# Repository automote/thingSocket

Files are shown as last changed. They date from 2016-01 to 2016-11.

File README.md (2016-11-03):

# thingSocket
__thingSocket__ is a Wi-Fi enabled socket/plug coupled with open APIs for people to develop, deploy or even clone.

__thingSocket__ is an attempt to promote IoT by providing open and hackable devices that you use everyday. Devices like bulbs, sockets, presence detectors and many more. The idea revolves around identifying frequently accessed devices and converting them into IoT devices by adding Wi-Fi, BLE or ZigBee capabilities.

We are starting with a Wi-Fi Socket and a Wi-Fi Bulb. These devices have the crowd favourite ESP8266 modules and we are planning to keep the hardware and software design open. This would encourage school and college students and even IoT enthusiasts to get into the IoT Bandwagon.

## Software
The software is completely written in __Arduino IDE__, so anyone familiar with the IDE can tinker with the code and personalise the device according to his taste.
The Algorithmic flow chart is mentioned below:
<p align="center">
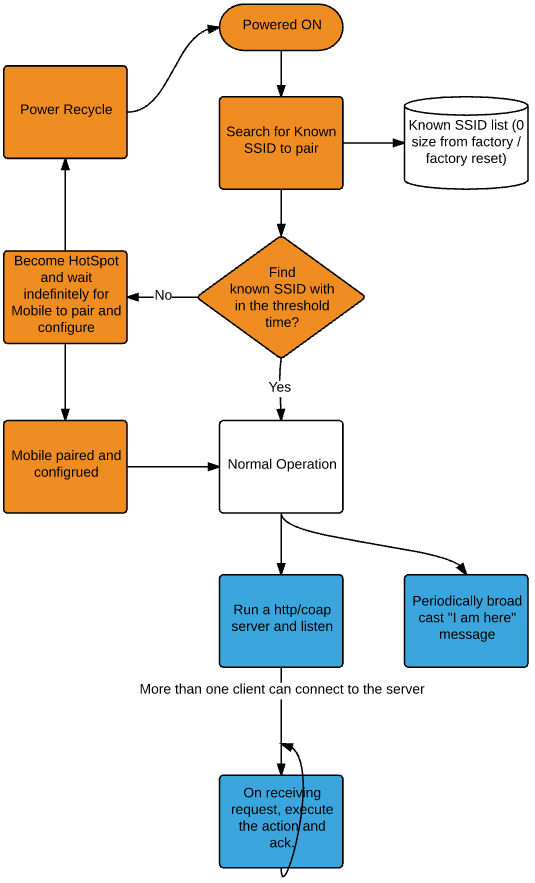
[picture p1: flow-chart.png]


The sketch will search for SSID and Password in EEPROM and tries to connect to the AP using the SSID and Password. If it fails then it boots into AP mode and asks for SSID and Password from the user. Connect to the thingSocket using the following: (SSID = thingSocket-<last 3 digits of MAC> and PASSWORD = 12345678)

While in __AP__ mode SSID and Password shoud be given using the following API. A webpage is also provided for entering SSID and Password if you are using the browser method.
- http://192.168.4.1/a?ssid="yourSSID"&pass="yourPSKkey"

The ESP in thingSocket acts as Webserver on port 80 and has the following __APIs__

The server will set a GPIO14 pin depending on the request
 - http://server_ip/plug/read will read all the plug status,
 - http://server_ip/plug/on will set the GPIO14 low,
 - http://server_ip/plug/off will set the GPIO14 high

Other functionality include
- http://server_ip/factoryreset will clear the EEPROM contents. Its serves the purpose of factory resetting the device
- http://server_ip/reboot will reboot the device after 10 seconds
- http://server_ip/setappliance will set the appliance location, type and name

where <I>server_ip</I> is the IP address of the ESP8266 module, will be printed to Serial when the module is connected.
- v0.5 is the standalone version
- v0.6 is currently developed version
- other sketches are the modules which were used in the v0.5 and v0.6
- v0.7 is in development which makes use of Wi-Fi Manager by <i>tzapu</i> https://github.com/tzapu/WiFiManager

## Hardware
The hardware is kept simple and has been designed in Eagle for anyone to use the schematic and board files to develop his own product. We are even planing to provide __GERBER__ files once we ready with the Design. 

- For Geeks, they can directly buy the hardware from us or can make their own device
- For Tinkerers, UART pins are provided to flash the code of their choice or improve upon the already existing code
- For ESP Extremists, they can flash NodeMCU firmware and start coding in Lua. Example codes will be provided soon

### Bugs
Code contains bugs some of which are critical while others are non critical
- Critical:
  - ~~while submitting the SSID and password the URL doesnot encode spacial characters~~
  - PLUG status is not stored in case of power cut
  - PLUG will remain off on restart
  - After reboot broadcast and multicast packets have decreased length
  - Watchdog timer setup to reset device if its in loop
  - thingSocket not rebooting properly after connection lost with router
   
- Non-Critical:
  - Previous SSID and password still remains in memory even after factory reset
  - ~~multicast packets are not broken into separate packets~~
  - ~~string of appl_type is not getting parsed properly~~
  - ~~AP mode remains on in STA mode as well~~

#### Inspiration
- http://www.esp8266.com/viewtopic.php?f=29&t=2520

#### Alpha Version
  - Alpha version is available for testing and verification
People who are interested can contact Lovelesh: lovelesh06101990@gmail.com

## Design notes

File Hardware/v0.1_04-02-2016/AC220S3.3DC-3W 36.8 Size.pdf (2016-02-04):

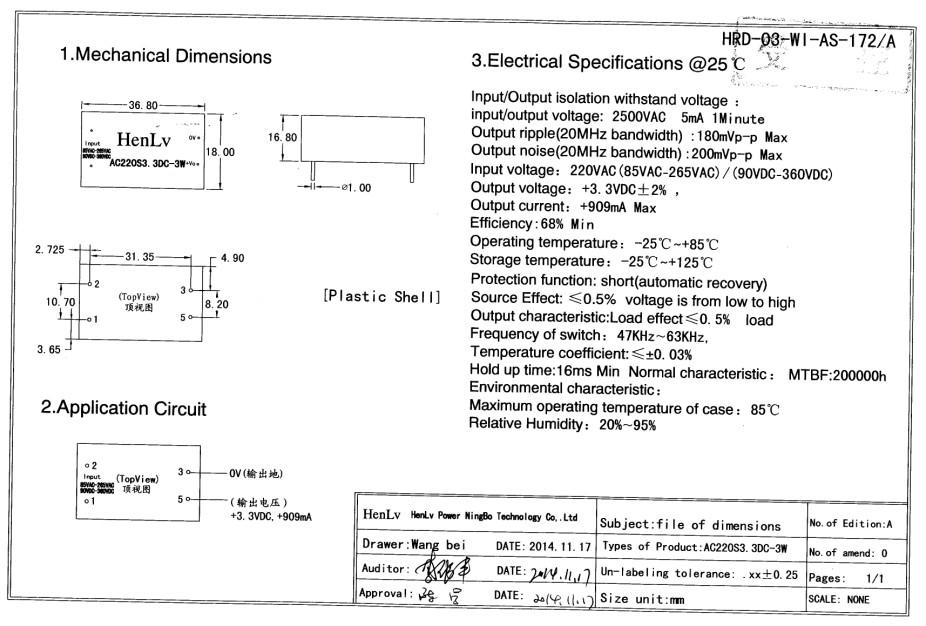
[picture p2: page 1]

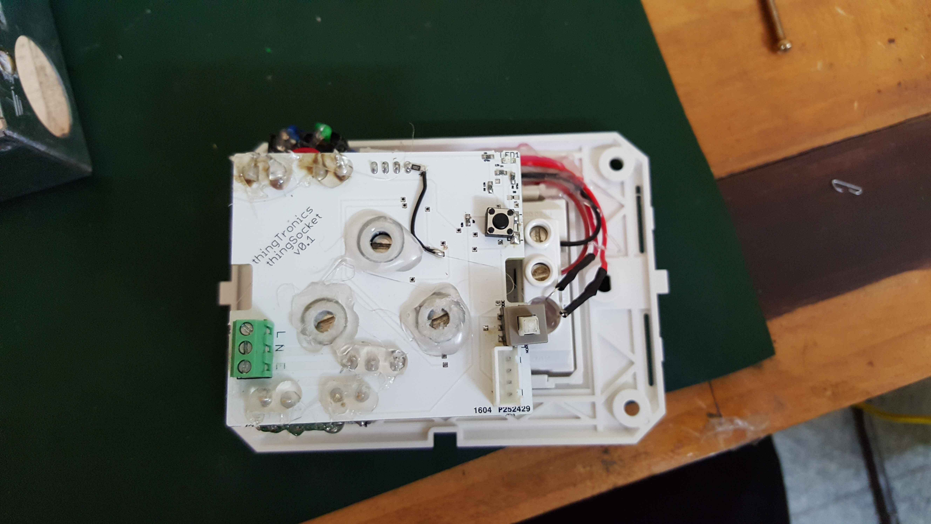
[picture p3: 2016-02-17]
Hardware/v0.1_04-02-2016/Images/dev-image-5.jpg

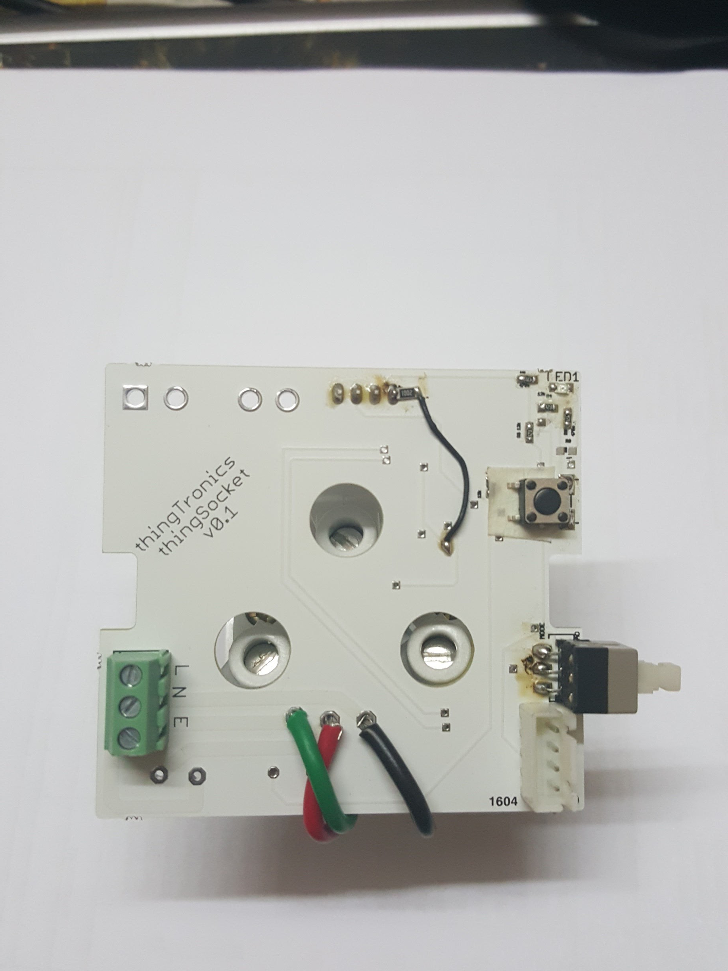
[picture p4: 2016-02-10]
Hardware/v0.1_04-02-2016/Images/dev-image-2.jpg

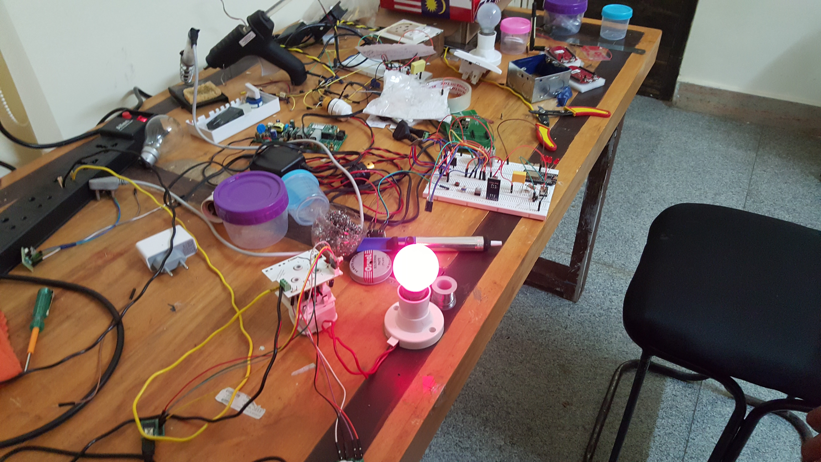
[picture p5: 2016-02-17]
Hardware/v0.1_04-02-2016/Images/dev-image-7.jpg

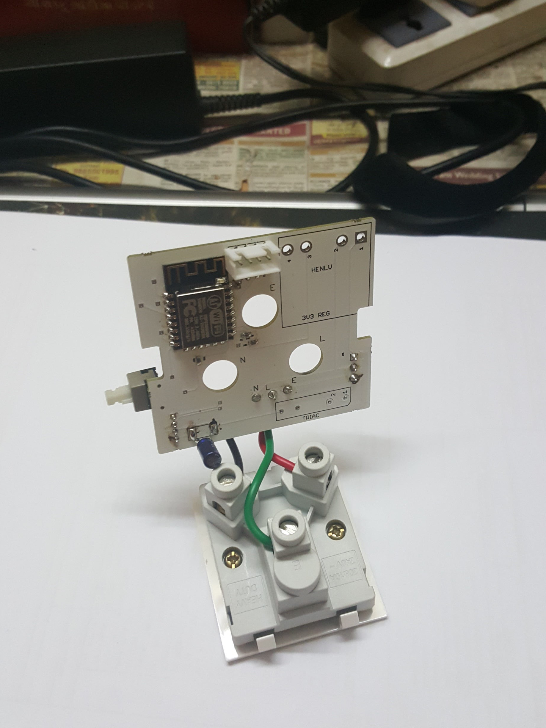
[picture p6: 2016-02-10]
Hardware/v0.1_04-02-2016/Images/dev-image-1.jpg

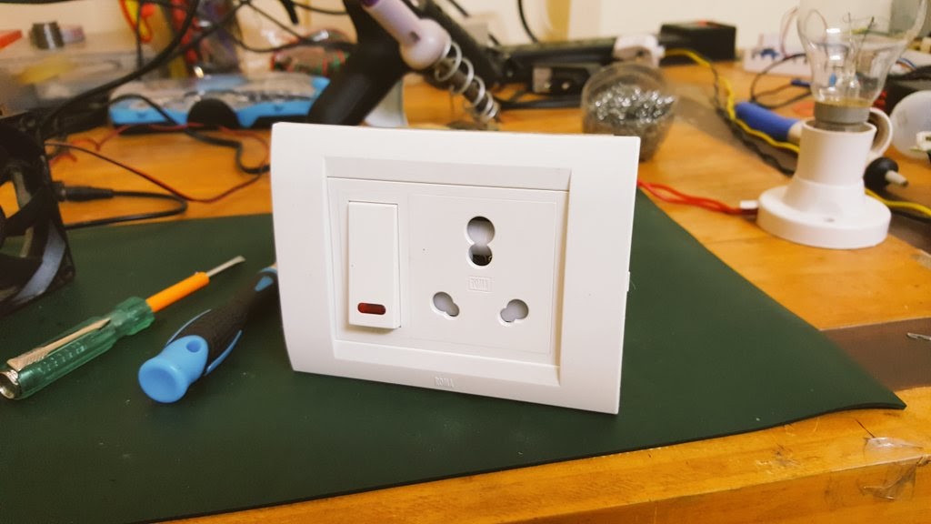
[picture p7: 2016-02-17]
Hardware/v0.1_04-02-2016/Images/dev-image-4.jpg

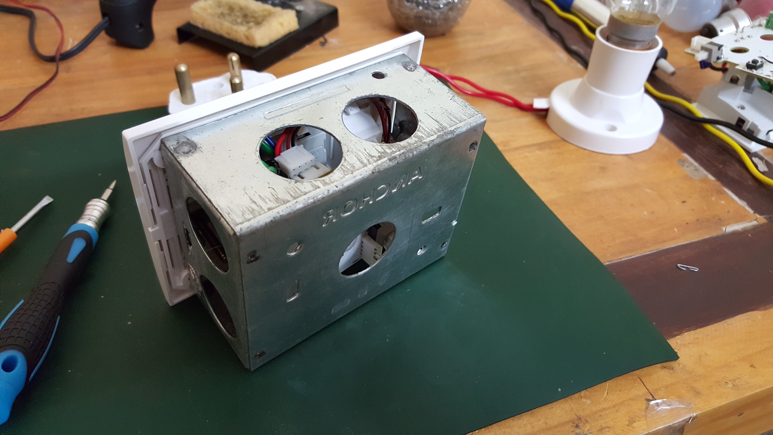
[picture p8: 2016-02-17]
Hardware/v0.1_04-02-2016/Images/dev-image-6.jpg

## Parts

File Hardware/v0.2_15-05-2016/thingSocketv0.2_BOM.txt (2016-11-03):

Partlist exported from P:/Arduino-sketches/thingSocket/Hardware/v0.2_15-05-2016/thingSocketv0.2.sch at 24-10-2016 13:41

Qty Value     Device                    Package               Parts                                    Description                                             
1             ESP8266-12EESP8266-ESP12E ESP8266-ESP12E        MDL1                                     ESP8266-12E with additional I/O and GPIO04/05 corrected 
1             JP2Q                      JP2Q                  TRIAC                                    JUMPER                                                  
1             LEDCHIPLED_0805           CHIPLED_0805          LED1                                     LED                                                     
2             M02                       02P                   LED, SWITCH                              AMP QUICK CONNECTOR                                     
1             M03SCREW                  SCREWTERMINAL-3.5MM-3 JP1                                      Header 3                                                
1             M04-V                     OUPIIN-4071V-4        PROG                                     Oupiin 4071 Series: 4 Pin Male                          
1             SWITCH-SPSTSMD2           SWITCH-SPDT-SMD       MODE                                     SPST Switch                                             
1             TL3302-J                  TL3303_J              RESET                                    E-Switch TL3302 Series Tactile Switch                   
1   0.1uf     CAP_POLSMD                VISHAY_C              C2                                       Capacitor Polarized                                     
6   12k       RESISTOR0805-RES          00805-RES             R1, R2, R3, R4, R5, R7                   Resistor                                                
1   1uf       CAP0805-CAP               0805-CAP              C1                                       Capacitor                                               
1   3V3 REG   HENLV3.3                  HENLV3.3PKG           HENLV                                    JUMPER                                                  
2   470e      RESISTOR0805-RES          0805-RES              R6, R9                                   Resistor                                                
1   NC        RESISTOR0805-RES          0805-RES              R8                                       Resistor                                                
8   TP-040    TP-040                    TP-040                TP4, TP5, TP6, TP7, TP8, TP9, TP10, TP11 TEST POINT                                              
3   TPPAD1-17 TPPAD1-17                 P1-17                 TP1, TP2, TP3                            Test pad

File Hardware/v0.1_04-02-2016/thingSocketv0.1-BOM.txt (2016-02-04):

Partlist exported from C:/Users/home/Documents/GitHub/hardware/wifi/gerb-pcbpower/esp.sch at 1/22/2016 1:38 PM

Part       Value     Device                    Package               Description                                             
4PINHEADER           M04-V                     OUPIIN-4071V-4        Oupiin 4071 Series: 4 Pin Male                          
C1         1uf       CAP0603-CAP               0603-CAP              Capacitor                                               
C2         0.1uf     CAP_POLSMD                VISHAY_C              Capacitor Polarized                                     
HENLV      3V3 REG   HENLV3.3                  HENLV3.3PKG           JUMPER                                                  
JP1                  M03SCREW                  SCREWTERMINAL-3.5MM-3 Header 3                                                
LED                  M02                       02P                   AMP QUICK CONNECTOR                                     
LED1                 LEDCHIPLED_0805           CHIPLED_0805          LED                                                     
MDL1                 ESP8266-12EESP8266-ESP12E ESP8266-ESP12E        ESP8266-12E with additional I/O and GPIO04/05 corrected 
MODE                 SWITCH-SPSTSMD2           SWITCH-SPDT-SMD       SPST Switch                                             
R1         12k       RESISTOR0603-RES          0603-RES              Resistor                                                
R2         12k       RESISTOR0603-RES          0603-RES              Resistor                                                
R3         12k       RESISTOR0603-RES          0603-RES              Resistor                                                
R4         12k       RESISTOR0603-RES          0603-RES              Resistor                                                
R5         12k       RESISTOR0603-RES          0603-RES              Resistor                                                
R6         470e      RESISTOR0603-RES          0603-RES              Resistor                                                
R7         12k       RESISTOR0603-RES          0603-RES              Resistor                                                
R8         NC        RESISTOR0603-RES          0603-RES              Resistor                                                
R9         470e      RESISTOR0603-RES          0603-RES              Resistor                                                
R10        12k       RESISTOR0603-RES          0603-RES              Resistor                                                
R11        10k       RESISTOR0603-RES          0603-RES              Resistor                                                
RESET                TL3302-J                  TL3303_J              E-Switch TL3302 Series Tactile Switch                   
SWITCH               M02                       02P                   AMP QUICK CONNECTOR                                     
TP1        TPPAD1-17 TPPAD1-17                 P1-17                 Test pad                                                
TP2        TPPAD1-17 TPPAD1-17                 P1-17                 Test pad                                                
TP3        TPPAD1-17 TPPAD1-17                 P1-17                 Test pad                                                
TP4        TP-040    TP-040                    TP-040                TEST POINT                                              
TP5        TP-040    TP-040                    TP-040                TEST POINT                                              
TP6        TP-040    TP-040                    TP-040                TEST POINT                                              
TP7        TP-040    TP-040                    TP-040                TEST POINT                                              
TP8        TP-040    TP-040                    TP-040                TEST POINT                                              
TP9        TP-040    TP-040                    TP-040                TEST POINT                                              
TP10       TP-040    TP-040                    TP-040                TEST POINT                                              
TP11       TP-040    TP-040                    TP-040                TEST POINT                                              
TRIAC                JP2Q                      JP2Q                  JUMPER

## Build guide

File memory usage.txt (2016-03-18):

memory usage:

0-31: ssid
32-95: password
100-115: zone
116-131: appliance type
132-147: applaince name

251: magic byte

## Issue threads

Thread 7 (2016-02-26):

Getting more done in GitHub with ZenHub

lovelesh, 2016-02-26:
Hola! @lovelesh has created a [ZenHub](http://www.zenhub.io) account for the **automote** organization. ZenHub is the leading team collaboration and project management solution built for GitHub.

----

#### How do I use ZenHub?

To get set up with ZenHub, all you have to do is **[download the browser extension](https://www.zenhub.io?utm_source=ZHOnboarding)** and log in with your GitHub account. Once you do, you’ll get access to ZenHub’s complete feature-set immediately.

#### What can ZenHub do?

ZenHub adds a series of enhancements directly inside the GitHub UI:

- Real-time, customizable task boards for GitHub issues;
- Burndown charts, estimates, and velocity tracking based on GitHub Milestones;
- Personal to-do lists and task prioritization;
- “+1” button for GitHub issues and comments;
- Drag-and-drop file sharing;
- Time-saving shortcuts like a quick repo switcher.

### [Add ZenHub to GitHub](https://www.zenhub.io?utm_source=ZHOnboarding)

_Still curious? See [more ZenHub features](https://www.zenhub.io/features?utm_source=ZHOnboarding) or read [user reviews](https://chrome.google.com/webstore/detail/zenhub-for-github/ogcgkffhplmphkaahpmffcafajaocjbd/reviews). This issue was written by your friendly ZenHub bot, posted by request from @lovelesh._

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

Closed 2016-04-08.

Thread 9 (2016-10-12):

Version / Previous SSID and password

elar-systems, 2016-10-12:
Hello,
I really like your development it helped a lot and I really am happy that I could find your codes as it helps a lot.
However, I have confusion about versions!
I could not compile version 2.0 as it needs 'css.h' and 'password.h' files which are missing!
However, the version 1.1 is compiling and working fine.
Now my question is that, why you said , in front page, that the version 0.6 is the current development one?
What version should I use to have the latest stable codes?

Also, i see you already now about this bug "Previous SSID and password still remains in memory even after factory reset".
Have you found any solution for that yet?

Thanks again...

lovelesh, 2016-10-12:
Hi,
Thanks for using my project. It really helps me as I hear from you guys that the code is working great.
You  are right: V2.0 is sitll in development as I wanted to use some CSS for look and feel, but then I thought an android App is even better. So I am working on it.

All versions from v0.6 to v1.1 will work with different features. In v1.1 you will get all the features.
If you can open wireshark you will notice a broadcast packet on port 5000 every 15 seconds. this can be used to as heartbeat packet for gateways.
Also whenever you change the status of plug, a notification broadcast is sent on 5002 port. This can be listened by other devices to understand status changes happening on remote devices.

I have tested on NodeMCU and my custom built hardware to control sockets
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

> Also, i see you already now about this bug "Previous SSID and password still remains in memory even after factory reset"
I still havent found any working solution, but you can use EEPROM erase code in arduino and burn the code again.

I will contact you if I need you help. And do keep sending me you feedback. Its valuable to me.

sghazagh, 2016-10-12:
Thanks for your reply,
I am using the code now and I really happy that I found it.
I have added another feature can be called by /config.
Then you can enter IP,Subnet and Gateway and these will be saved to eeprom from address 150.
at the time of start(reboot), I have added another function to check the IP,Subnet and Gateway.
Then connect to wifi_sta with set IP,Subnet and Mask.

That is actually very handy as you can change the IP address of the device through config page.
I can chare the code with you if you like to add it to the project.

I have tested and I am using that on "Wemos D1 mini Pro" and it works greate

sghazagh, 2016-10-12:
With regard to Android app, I have created an app that can send the URL through Internet to my device and reads the respond to update the status of buttons.
With this way,you can send whatever command which you like to your web server and control your device through Android app , similar way you can control over the web.

here is a snapshot of my app.
I also have added a sensor to read room Temperature and Humidity and show on my app everywhere I am, even out of the home...

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

lovelesh, 2016-10-13:
That's GREAT.

How are you solving the problem of addressing a device behind NAT? I am facing similar issues and I have to use a cloud server. I am looking for an approach that skips this cloud server.

sghazagh, 2016-10-13:
That's actually is simple and you do not need Cloud Server at all.
You need to open a port on your router to point to your device IP and port.
That's why we normally need to set the static IP for our devices.

Suppose your device has address 192.168.1.20 and the web server is running on port 8080 (do not set port 80 as default on devise web server, 80 is common for http and you really do not need that port)

And also imagine your outside IP address is "123.123.123.123".
And if you do not have static IP address, then you have to use some services like "dyndns".

anyway, you need a link like:
http://123.123.123.0:8080/plug/on
or
http://lovelesh.dyndns.com:8080/plug/on  (sample)

to use outside of your home to access the web server on your device. Same concept on Android app.
You will send the URL request to above addresses from your Android app.
(I am using Google Volley Library for transmitting network request... it's quite extensive and works great )

Then the request first comes to your router and your router forwards the request to port 8080 of your deceive (or whatever port you want to set internally for your device) .

If your router has the loopback capability, which most of the recent router does, you also can use the external IP address/dyndns address to use within your LAN too.

Hope it helps...

elar-systems, 2016-10-13:
I think I have found the issue for memorizing the SSID and Password after factory reset.
I read somewhere that the ESP8266, keeps the wifi connection.
To reset and erase the connection info, we have to do this:

On setup() section:
```
WiFi.persistent(false); // Do not memorise new connections
// ESP.flashEraseSector(0x3fe); // Erase remembered connection info. (Only do this once).
```
I haven't tried it yest but will do when I get home and can work on it...

elar-systems, 2016-10-13:
Hi, Lovelesh,
I can confirm that the SSID and Password is written in address  0x3fe000 and after /factoryreset the data still is there.
You can dump the data on that address and have a look in HEX editor yourself.
here is the command you can dump the data on that address by "esptools.py":
`esptool.py -p COM3 read_flash 0x3fe000 0x2000 d:\flashdump.bin`

So, you have to find the way to clear this segment and implement that in your code.
I believe the bellow code should works but you have to manage to run the 'ESP.flashEraseSector(0x3fe);" part of that once and at /factoryreset time.
Perhaps a flag can trig it:
```
WiFi.persistent(false); // Do not memorize new connections
ESP.flashEraseSector(0x3fe); // Erase remembered connection info. (Only do this once).
```

Hope we see you fixed that in next release.

lovelesh, 2016-10-14:
@elar-systems this is a very nice idea.
Make shift solution could be to use these APIs in **factory reset** section of the code.
I will try it out and update the code

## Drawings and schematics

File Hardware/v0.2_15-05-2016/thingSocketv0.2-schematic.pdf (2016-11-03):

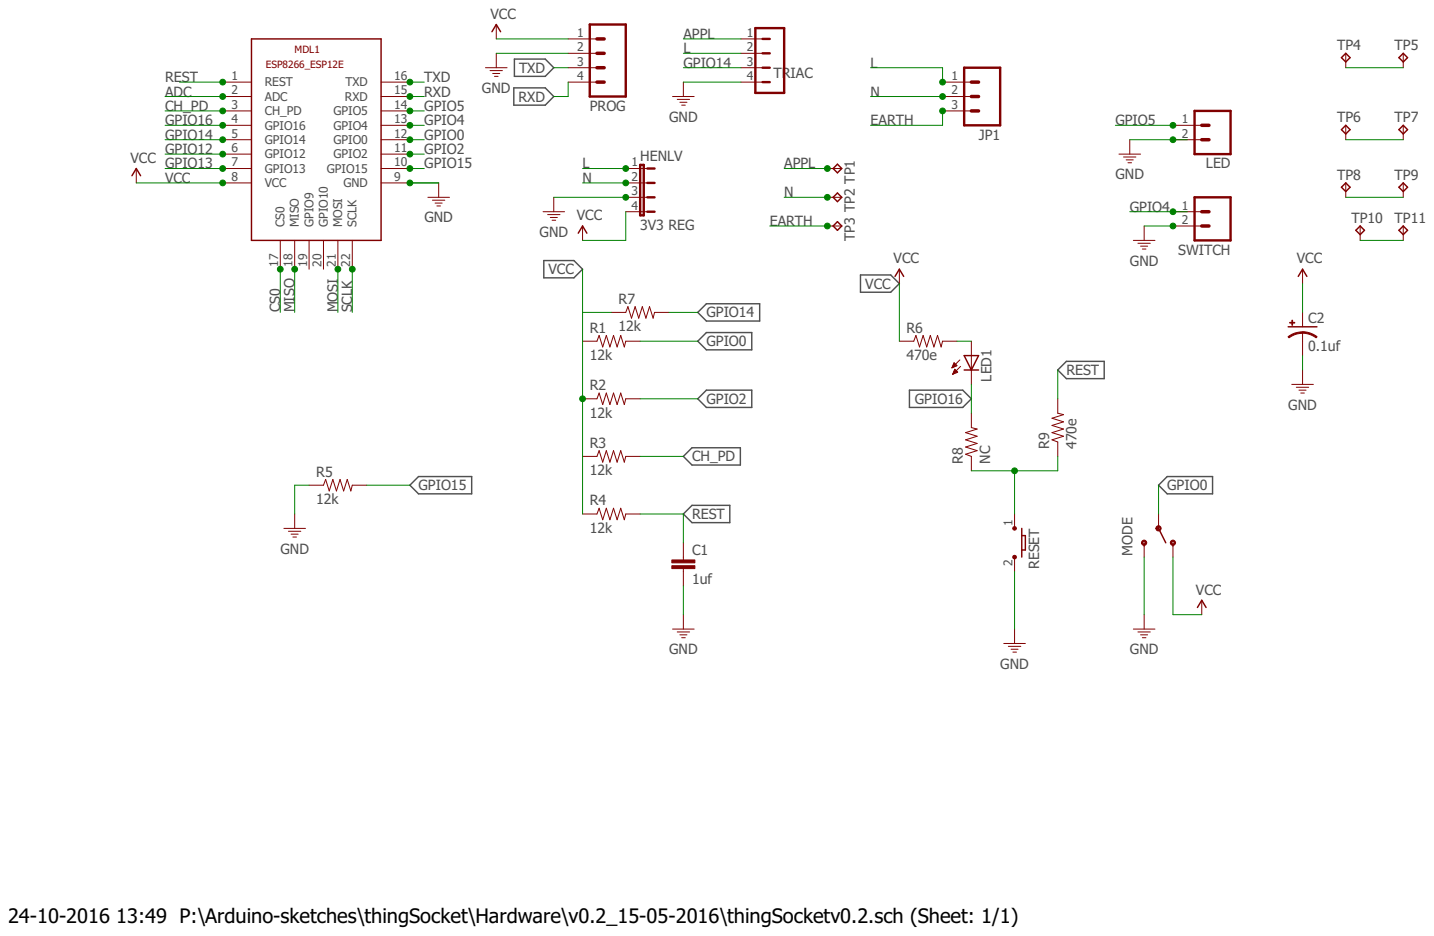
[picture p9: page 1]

24-10-2016 13:49 P:\Arduino-sketches\thingSocket\Hardware\v0.2_15-05-2016\thingSocketv0.2.sch (Sheet: 1/1)

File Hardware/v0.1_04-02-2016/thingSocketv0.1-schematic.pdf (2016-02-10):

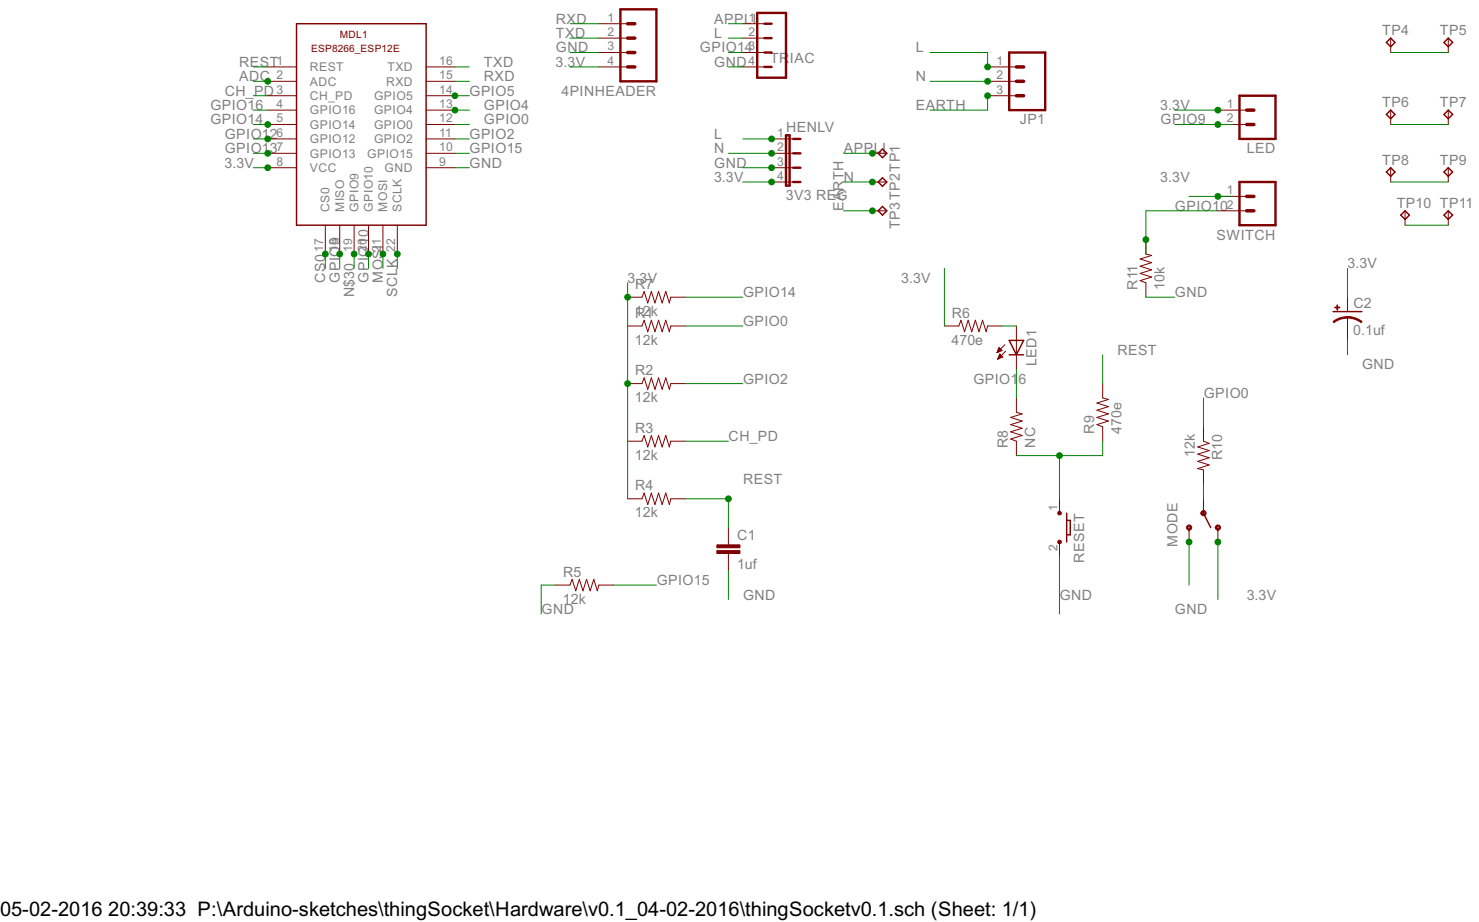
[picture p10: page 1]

05-02-2016 20:39:33 P:\Arduino-sketches\thingSocket\Hardware\v0.1_04-02-2016\thingSocketv0.1.sch (Sheet: 1/1)

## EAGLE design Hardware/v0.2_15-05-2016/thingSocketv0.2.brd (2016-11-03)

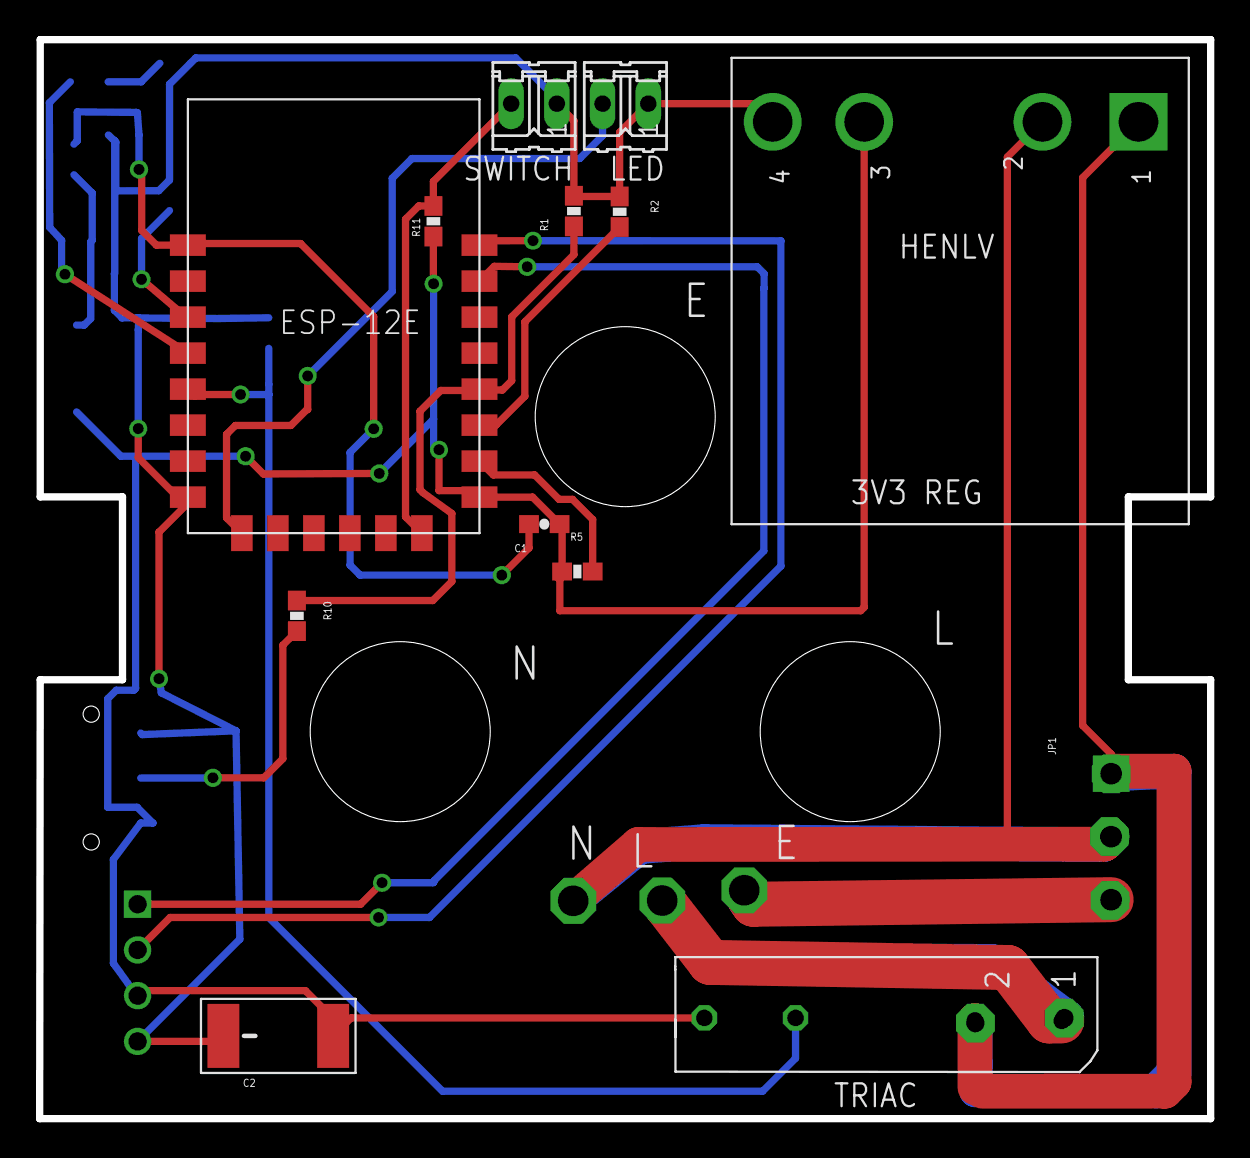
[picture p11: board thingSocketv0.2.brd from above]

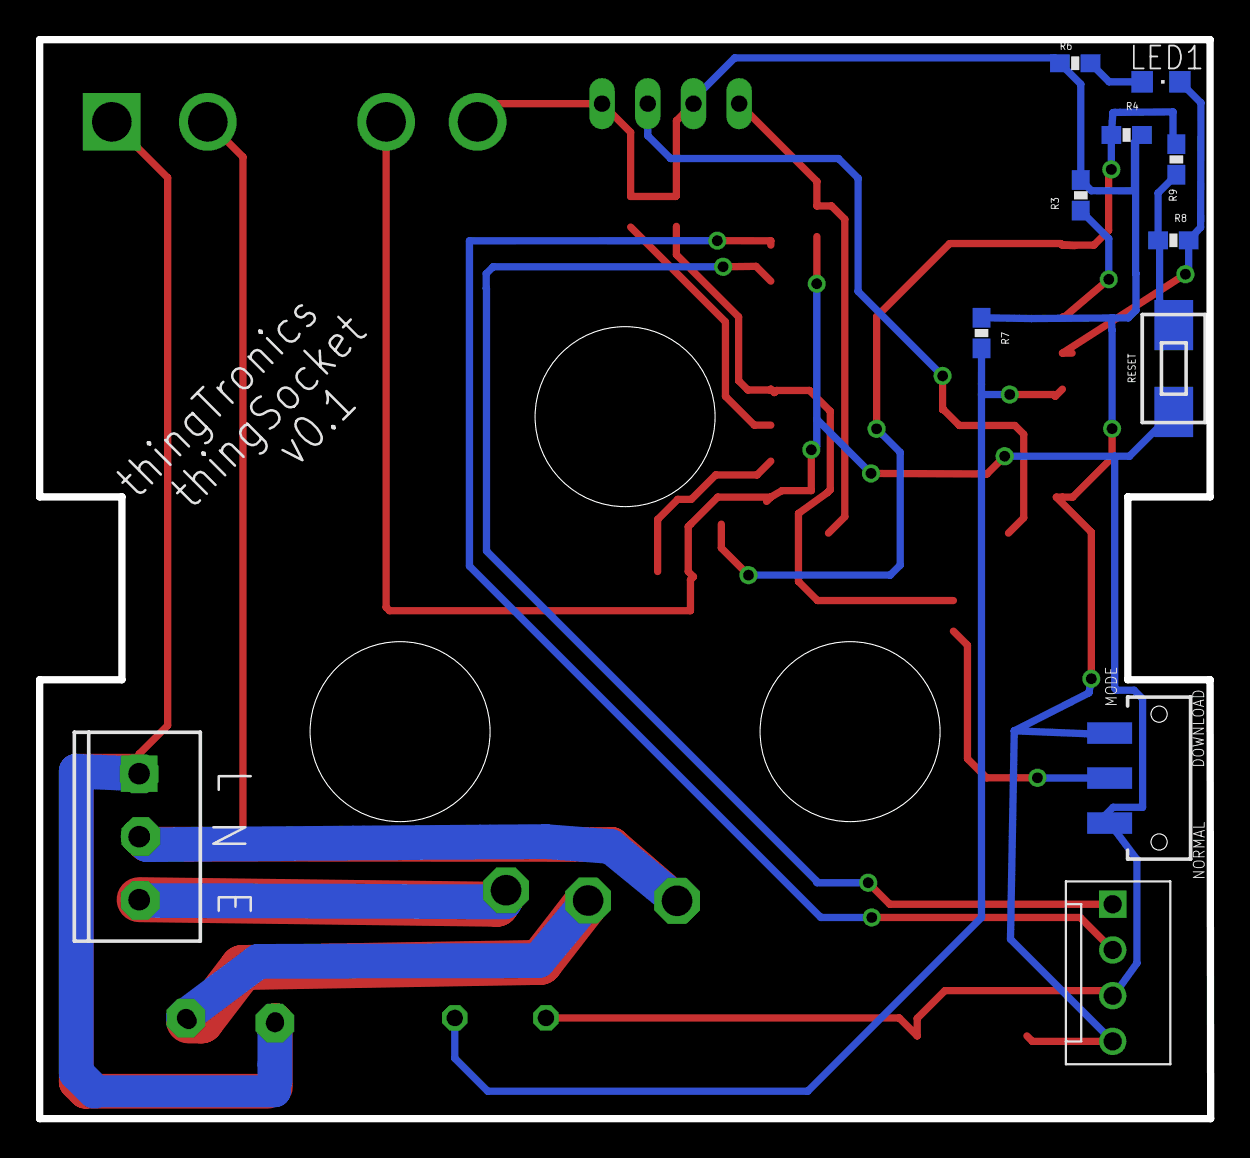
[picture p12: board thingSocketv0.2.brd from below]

Board: 2 copper layers, 65.1 x 59.9 mm, 35 parts (11 on the bottom side), 24 nets.

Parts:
4PINHEADER: OUPIIN-4071V-4
C1: 1uf; 0603-CAP
C2: 0.1uf; VISHAY_C
DRILEGEND: DRILEGEND
HENLV: 3V3 REG; HENLV3.3PKG
JP1: SCREWTERMINAL-3.5MM-3
LED: 02P
LED1: CHIPLED_0805
MDL1: ESP8266-ESP12E
MODE: SWITCH-SPDT-SMD
R1, R2, R3, R4, R5, R7, R10: 12k; 0603-RES
R6, R9: 470e; 0603-RES
R8: NC; 0603-RES
R11: 10k; 0603-RES
RESET: TL3303_J
SWITCH: 02P
TP1, TP2, TP3: TPPAD1-17; P1-17
TP4, TP5, TP6, TP7, TP8, TP9, TP10, TP11: TP-040
TRIAC: JP2Q

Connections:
3.3V: 4PINHEADER.4, C2.+, HENLV.4, LED.1, MDL1.8, MODE.1, R1.1, R2.1, R3.1, R4.1, R6.1, R7.1, SWITCH.1
APPLI: TP1.1, TRIAC.1
CH_PD: MDL1.3, R3.2
EARTH: JP1.3, TP3.1
GND: 4PINHEADER.3, C1.2, C2.-, HENLV.3, MDL1.9, MODE.3, R5.1, R11.1, RESET.2, TRIAC.4
GPIO0: MDL1.12, R1.2, R10.1
GPIO2: MDL1.11, R2.2
GPIO9: LED.2, MDL1.18
GPIO10: MDL1.20, R11.2, SWITCH.2
GPIO14: MDL1.5, R7.2, TRIAC.3
GPIO15: MDL1.10, R5.2
GPIO16: LED1.C, MDL1.4, R8.2
L: HENLV.1, JP1.1, TRIAC.2
N: HENLV.2, JP1.2, TP2.1
unnamed: TP4.1, TP5.1
unnamed: TP6.1, TP7.1
unnamed: R8.1, R9.1, RESET.1
unnamed: TP8.1, TP9.1
unnamed: TP10.1, TP11.1
unnamed: MODE.2, R10.2
unnamed: LED1.A, R6.2
REST: C1.1, MDL1.1, R4.2, R9.2
RXD: 4PINHEADER.1, MDL1.15
TXD: 4PINHEADER.2, MDL1.16

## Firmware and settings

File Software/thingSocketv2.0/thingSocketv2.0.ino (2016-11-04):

/*
 *  This sketch is the source code for thngSocket.
 *  The sketch will search for SSID and Password in EEPROM and
 *  tries to connect to the AP using the SSID and Password.
 *  If it fails then it boots into AP mode and asks for SSID and Password from the user
 *  API for AP (SSID = thingSocket-<last 3 digits of MAC> and PASSWORD = 12345678)
 *    http://192.168.4.1/a?ssid="yourSSID"&pass="yourPSKkey"
 *  A webpage is also provided for entering SSID and Password if you are using the browser method.
 *  The server will set a GPIO14 pin depending on the request
 *    http://server_ip/resource will read all the plug status,
 *    http://server_ip/resource/set?res=0&val=0 will set the GPIO14 low,
 *    http://server_ip/resource/set?res=0&val=100 will set the GPIO14 high
 *    http://server_ip/factoryreset will clear the EEPROM contents. Its serves the purpose of factory resetting the device.
 *    http://server_ip/reboot will reboot the device after 10 seconds
 *    http://server_ip/setappliance will set the appliance location, type and name
 *  server_ip is the IP address of the ESP8266 module, will be
 *  printed to Serial when the module is connected.
 *  The complete project can be cloned @ https://github.com/automote/thingSocket.git
 *
 *  Inspired by:
 *  https://github.com/chriscook8/esp-arduino-apboot
 *  This example code is under GPL v3.
 *  modified 2 November 2016
 *  by Lovelesh Patel
 */

#include <ESP8266WiFi.h>
#include <ESP8266mDNS.h>
#include <WiFiClient.h>
#include <EEPROM.h>

// GPIO14 connected to Socket, GPIO5 to SWITCH, GPIO4 to SWITCH_LED
// GPIO16 is for status
#define PLUG 14
#define CONNECT 16
#define SWITCH_LED 4
#define SWITCH 5

#define BROADCAST_PORT 5000   // Port for sending general broadcast messages
#define NOTIFICATION_PORT 5002     // Port for notification broadcasts

// For debugging interface
#define DEBUG 1
#define MAX_RETRIES 20  // Max retries for checking wifi connection
#define MAX_RESOURCES 1

MDNSResponder mdns;
// Create an instance of the Web server
// specify the port to listen on as an argument
WiFiServer server(80);

// Global Constant
const char* company_name = "thingTronics";
const char* hardware_version = "v2.0";
const char* software_version = "v2.0";
const char APpsk[] = "12345678";
const int resource_number = 0;

// Global Variable
String st;
String hostName = "thingSocket-";
String zone, appl_type, appl_name;
String macID;
static unsigned char bcast[4] = { 255, 255, 255, 255 } ;   // broadcast IP address
unsigned int count = 0;
#ifdef DEBUG
volatile unsigned int num = 0;
#endif

// Reboot flag to reboot the device when necessary
bool reboot_flag = false;
bool configure_flag = false;

// Create an instance of the UDP server
WiFiUDP Udp;

// Function Declaration
void InitHardware(void);
void BroadcastSetup(void);
bool SSIDSearch(void);
void ZoneSearch(void);
bool TestWifi(void);
void WebServiceInit(void);
void MDNSService(void);
void WebServiceDaemon(bool webtype);
void WebService(bool webtype);
void UpdatePlugNLED(int plug, int value);
void SetupAP(void);
void Broadcast(void);
void NotificationBroadcast(int which_plug, int state);
void UrlDecode(char *src);
void pin_ISR(void);
void myDelay(int);
void WriteInitalConfig(void);
void ReadConfig(void);

void setup() {
  bool AP_required = false;
  // Initialise the hardware
  InitHardware();

  // Setting up the broadcast service
  BroadcastSetup();

  // Search for SSID and password from the EEPROM first and try to connect to AP
  AP_required = !SSIDSearch();
  ZoneSearch();

  // If it fails then make yourself AP and ask for SSID and password from user
  if (AP_required) {
    SetupAP();
  }
  // Initialise the webserver for direct initialization
  WebServiceInit();
}

void loop() {
  if (count % 1200 == 0) {
    // Test WiFi connection every minute and set the reboot flag if necessary
    // count is incremented roughly every 50ms
    Serial.println("checking wifi connection");
    reboot_flag = !TestWifi();
  }
  // Serving the requests from the client
  WebService(0);
  if (reboot_flag) {
    Serial.println("Rebooting device");
    delay(10000);
    ESP.restart();
  }
}

void InitHardware(void) {
  Serial.begin(115200);
  // Specify EEPROM block
  EEPROM.begin(512);
  delay(10);
  Serial.println();
  Serial.println("Setting up the Hardware");

  // prepare PLUG to control the socket i.e. GPIO14
  pinMode(PLUG, OUTPUT);
  digitalWrite(PLUG, LOW);

  // prepare the CONNECT LED i.e. GPIO16
  pinMode(CONNECT, OUTPUT);
  digitalWrite(CONNECT, HIGH);

  // prepare the SWITCH and SWITCH_LED i.e. GPIO4 and GPIO5
  pinMode(SWITCH, INPUT_PULLUP);
  pinMode(SWITCH_LED, OUTPUT);
  digitalWrite(SWITCH_LED, digitalRead(PLUG));
  attachInterrupt(digitalPinToInterrupt(SWITCH), pin_ISR, CHANGE);
  
  // Set the thingSocket into STATION mode
  WiFi.mode(WIFI_STA);
  
  // Get the mac address of the ESP module
  uint8_t mac[WL_MAC_ADDR_LENGTH];
  WiFi.macAddress(mac);
  macID = String(mac[WL_MAC_ADDR_LENGTH - 3], HEX) +
				 String(mac[WL_MAC_ADDR_LENGTH - 2], HEX) +
                 String(mac[WL_MAC_ADDR_LENGTH - 1], HEX);
  macID.toUpperCase();
  hostName += macID;
}

void BroadcastSetup(void) {
  Udp.begin(BROADCAST_PORT);
  Udp.begin(NOTIFICATION_PORT);
}

bool SSIDSearch(void) {
  Serial.println("Start SSID search from EEPROM");
  // Read EEPROM for SSID and Password
  Serial.println("Reading SSID from EEPROM");
  String essid;
  for (int i = 0; i < 32; ++i) {
    essid += char(EEPROM.read(i));
  }
#ifdef DEBUG
  Serial.print("SSID: ");
  Serial.println(essid);
  Serial.println("Reading Password from EEPROM");
#endif

  String epass = "";
  for (int i = 32; i < 96; ++i) {
    epass += char(EEPROM.read(i));
  }
#ifdef DEBUG
  Serial.print("PASS: ");
  Serial.println(epass);
#endif

  if ( essid.length() > 1 ) {
    // Try to connect to AP with given SSID and Password
    WiFi.begin(essid.c_str(), epass.c_str());
    if ( TestWifi() ) {
      Serial.println("Wifi test successful");
      return true;
    }
    else {
      Serial.println("Wifi test failed");
      return false;
    }
  }
}

void ZoneSearch(void) {
	if (EEPROM.read(500) != 251) {
		//if not load default config files to EEPROM
		WriteInitalConfig();
	}
	// Read the config settings from EEPROM
	ReadConfig(); 
}

bool TestWifi(void) {
  int retries = 0;
  WiFi.mode(WIFI_STA);
  Serial.println("Waiting for Wi-Fi to connect");
  while ( retries < MAX_RETRIES ) {
    if (WiFi.status() == WL_CONNECTED) {
      Serial.println("Connected");
      digitalWrite(CONNECT, LOW);
      return true;
    }
    delay(500);
    Serial.print(WiFi.status());
    retries++;
  }
  Serial.println("Connect timed out");
  digitalWrite(CONNECT, HIGH);
  return false;
}

void WebServiceInit(void) {
#ifdef DEBUG 
 Serial.println("");
  Serial.println("Initializing Web Services");
  Serial.println(WiFi.localIP());
  Serial.println(WiFi.softAPIP());
#endif
  // Starting web server
  server.begin();
  Serial.println("Server started");

  // Starting mDNS Service
  MDNSService();
}

void MDNSService(void) {
  // Set up mDNS responder:
  // - first argument is the domain name, in this example
  //   the fully-qualified domain name is "esp8266.local"
  // - second argument is the IP address to advertise
  //   we send our IP address on the WiFi network
  int hostName_len = hostName.length() + 1; 
  char hostNameChar[hostName_len];
  hostName.toCharArray(hostNameChar, hostName_len);
  if (!MDNS.begin(hostNameChar)) {
    Serial.println("Error setting up MDNS responder!");
    return;
  }
  Serial.println("mDNS responder started");

  // Add service to MDNS-SD
  MDNS.addService("http", "tcp", 80);
  return;
}

void WebServiceDaemon(bool webtype) {
  while (1) {
    // Running Web Service
    WebService(webtype);
    if (reboot_flag) {
      delay(10000);
      ESP.restart();
    }
    // reboot the device in AP mode if no configuration is done in 10 mins
    if (count % 12000 == 0 && webtype) {
      reboot_flag = 1;
    }
  }
}

void WebService(bool webtype) {
  // Match the request
  int which_plug = -1; // Selects the plug to use
  int value = -1; // Initial state

  // Check if a client has connected
  WiFiClient client = server.available();
  if (!client) {
    if (count % 60 == 0) {
      Broadcast();
    }
    delay(50);
    count++;
    return;
  }
  Serial.println("");
  Serial.println("New client");

  // Wait for data from client to become available
  while (client.connected() && !client.available()) {
    delay(1);
  }

  // Read the first line of HTTP request
  String req = client.readStringUntil('\r');

  // First line of HTTP request looks like "GET /path HTTP/1.1"
  // Retrieve the "/path" part by finding the spaces
  int addr_start = req.indexOf(' ');
  int addr_end = req.indexOf(' ', addr_start + 1);
  if (addr_start == -1 || addr_end == -1) {
    Serial.print("Invalid request: ");
#ifdef DEBUG  
  Serial.println(req);
#endif
    return;
  }
  req = req.substring(addr_start + 1, addr_end);
#ifdef DEBUG
  Serial.print("Request: ");
  Serial.println(req);
#endif
  client.flush();
  String s = "HTTP/1.1 200 OK\r\nContent-Type: text/html\r\n\r\n<!DOCTYPE HTML>\r\n<html>";
  if (webtype) {
    if (req == "/") {
      IPAddress ip = WiFi.softAPIP();
      String ipStr = String(ip[0]) + '.' + String(ip[1]) + '.' + String(ip[2]) + '.' + String(ip[3]);
      s += "Hello from thingSocket at ";
      s += ipStr;
      s += "<p>";
      s += st;
      s += "<form method='get' action='a'><label>SSID: </label><input name='ssid' length=32><input name='pass' length=64><input name='devicepassword' length=8><input type='submit'></form>";

      Serial.println("Sending 200");
    }
    else if ( req.startsWith("/a?ssid=") ) {
      // /a?ssid="SSID"&pass="PSK Key"&devicepassword=1234567
      Serial.println("clearing eeprom");
      for (int i = 0; i < 96; ++i) {
        EEPROM.write(i, 0);
      }
      String qssid;
      qssid = req.substring(8, req.indexOf('&'));
      char bssid[32];
      qssid.toCharArray(bssid, qssid.length() + 1);
      UrlDecode(bssid);
      qssid = String(bssid);
#ifdef DEBUG      
	  Serial.println(qssid);
      Serial.println("");
#endif
	  String qpass;
	  qpass = req.substring(req.indexOf('&'), req.lastIndexOf('&'));
      qpass = qpass.substring(qpass.indexOf('=') + 1);
      char bpass[64];
      qpass.toCharArray(bpass, qpass.length() + 1);
      UrlDecode(bpass);
      qpass = String(bpass);
#ifdef DEBUG      
	  Serial.println(qpass);
      Serial.println("");
#endif
	  String qdevpass;
	  qdevpass = req.substring(req.lastIndexOf('=') + 1);
	  char bdevpass[8];
      qdevpass.toCharArray(bdevpass, qdevpass.length() + 1);
	  UrlDecode(bdevpass);
	  qdevpass = String(bdevpass);
#ifdef DEBUG	  
	  Serial.println(qdevpass);
	  Serial.println("");
#endif	  
      Serial.println("writing ssid to EEPROM");
      for (int i = 0; i < qssid.length(); ++i) {
        EEPROM.write(i, qssid[i]);
#ifdef DEBUG		
        Serial.print("Wrote: ");
        Serial.println(qssid[i]);
#endif		
      }
      Serial.println("writing eeprom pass:");
      for (int i = 0; i < qpass.length(); ++i) {
        EEPROM.write(32 + i, qpass[i]);
#ifdef DEBUG
        Serial.print("Wrote: ");
        Serial.println(qpass[i]);
#endif		
      }
      EEPROM.commit();
      s += "Hello from thingSocket ";
#ifdef DEBUG
      s += "Found ";
      s += req;
#endif	  
      s += "<p> Details saved to EEPROM... System will reboot in 10 seconds";
      reboot_flag = true;
    }
    else {
      s = "HTTP/1.1 404 Not Found\r\n\r\n<!DOCTYPE HTML>\r\n<html>";
      s += "<h1>404</h1><h3>Page Not Found</h3>";
      Serial.println("Sending 404");
    }
  }
  else {
    if (req == "/") {
      s += "Hello from thingSocket";
      s += "<p>";
      Serial.println("Sending 200");
    }
	else if (req.startsWith("/resource")) {
		s += "Hello from thingSocket </br>";
		s += "<form method='get' action='/resource/set'><label>Resource No: </label><input name='res' length=2><label>Value: </label><input name='val' length=3><input type='submit'></form>";
		value = -2;
		which_plug = PLUG;
	  
		if (req.startsWith("/resource/set?res=")) {
			//resource/set?res=0&val=100
			// No need to acquire resource argument as thingSocket has only 1 resource
			// By Default res = 0

			// Getting value of resource
			String val = req.substring(req.lastIndexOf('=') + 1);
			value = val.toInt();
		}

		// Prepare the response
		if (value >= 0 && value <= 100) {
			// Update the status of PLUG and SWITCH_LED
			UpdatePlugNLED(which_plug, value);
			s += "Resource 0";
			s += " = ";
			s += String((digitalRead(PLUG) > 0) ? 100 : 0);
			s += "<br>"; // Go to the next line.
		}
		else if (value == -2) {
			s += "Resource 0";
			s += " = ";
			value = (digitalRead(PLUG) > 0) ? 100 : 0;
			s += String(value);
			s += "<br>"; // Go to the next line.
#ifdef DEBUG
			Serial.println(value); // Debug the value
#endif
			// Sent the queried resource via notification
			NotificationBroadcast(which_plug, value);
		}
		else {
			s += "Invalid Request<br> Try /resource/set?res=0&val=0|100|-2";
		}
    }
    else if (req == "/setappliance") {
      s += "Hello from thingSocket </br>";
      s += "Please fill";
      s += "<form method='get' action='appl'><label>Resource No: </label><input name='res' length=2><label>Zone: </label><input name='zone' length=15><label>Appliance Type: </label><input name='appl_type' length=15><label>Appliance Name: </lable><input name='appl_name' length=15><input type='submit'></form>";

      Serial.println("Sending 200");
    }
    else if ( req.startsWith("/appl?res=")) {
      // /appl?res=0&zone=hall&appl_type=bulb&appl_name=user-name
      // Resource for thingSocket is always 0

      zone = req.substring(req.indexOf('&') + 1, req.lastIndexOf('&'));
      // zone=hall&appl_type=bulb
      appl_type = zone.substring(zone.lastIndexOf('=') + 1);
      zone = zone.substring(zone.indexOf('=') + 1, zone.indexOf('&'));
      char qzone[16];
      zone.toCharArray(qzone, zone.length() + 1);
      UrlDecode(qzone);
      zone = String(qzone);
#ifdef DEBUG
	  Serial.println(zone);
#endif        
      char qappl_type[16];
      appl_type.toCharArray(qappl_type, appl_type.length() + 1);
      UrlDecode(qappl_type);
      appl_type = String(qappl_type);
#ifdef DEBUG      
	  Serial.println(appl_type);
#endif
      appl_name = req.substring(req.lastIndexOf('=') + 1);
      char qappl_name[16];
      appl_name.toCharArray(qappl_name, appl_name.length() + 1);
      UrlDecode(qappl_name);
      Serial.println(appl_name);
#ifdef DEBUG      
	  appl_name = String(qappl_name);
#endif
	  Serial.println("clearing eeprom");
	  for (int i = 100; i < 155; ++i) {
		EEPROM.write(i, 0);
      }
	  
      Serial.println("writing eeprom Zone:");
      for (int i = 0; i < zone.length(); ++i) {
        EEPROM.write(100 + i, zone[i]);
#ifdef DEBUG      
		Serial.print("Wrote: ");
        Serial.println(zone[i]);
#endif		
      }
      Serial.println("writing eeprom Appl_type:");
      for (int i = 0; i < appl_type.length(); ++i) {
        EEPROM.write(116 + i, appl_type[i]);
#ifdef DEBUG		
        Serial.print("Wrote: ");
        Serial.println(appl_type[i]);
#endif		
      }
      Serial.println("writing eeprom Appl_name:");
      for (int i = 0; i < appl_name.length(); ++i) {
        EEPROM.write(132 + i, appl_name[i]);
#ifdef DEBUG		
        Serial.print("Wrote: ");
        Serial.println(appl_name[i]);
#endif		
      }
      EEPROM.commit();
      s += "Hello from thingSocket ";
#ifdef DEBUG	  
      s += "Found ";
      s += req;
#endif	  
      s += "<p> Details saved to EEPROM...";
      configure_flag = true;
      NotificationBroadcast(which_plug,value);
    }

    else if ( req.startsWith("/factoryreset") ) {
      s += "Hello from thingSocket";
      s += "<p>Factory Resetting the device<p>";
      Serial.println("Sending 200");
      
	  // Writing default configuration
	  WriteInitalConfig();
	  reboot_flag = true;
    }
    else if ( req.startsWith("/reboot")) {
      s += "Rebooting thingSocket";
      Serial.println("Sending 200");
      reboot_flag = true;
    }
    else {
      s = "HTTP/1.1 404 Not Found\r\n\r\n<!DOCTYPE HTML>\r\n<html>";
      s += "<h1>404</h1>Page Not Found";
      Serial.println("Sending 404");
    }
  }
  s += "</html>\r\n\r\n";
  client.print(s);
  Serial.println("Client disconnected");

  // The client will actually be disconnected
  // when the function returns and 'client' object is detroyed
  return;
}

void SetupAP(void) {

  WiFi.mode(WIFI_STA);
  WiFi.disconnect();
  delay(100);
  int n = WiFi.scanNetworks();
  Serial.println("scan done");
  if (n == 0)
    Serial.println("no networks found");
  else {
    Serial.print(n);
    Serial.println(" networks found");
    for (int i = 0; i < n; ++i) {
      // Print SSID and RSSI for each network found
      Serial.print(i + 1);
      Serial.print(": ");
      Serial.print(WiFi.SSID(i));
      Serial.print(" (");
      Serial.print(WiFi.RSSI(i));
      Serial.print(")");
      Serial.println((WiFi.encryptionType(i) == ENC_TYPE_NONE) ? " " : "*");
      delay(10);
    }
  }
  Serial.println("");
  st = "<ul>";
  for (int i = 0; i < n; ++i) {
    // Print SSID and RSSI for each network found
    st += "<li>";
    st += i + 1;
    st += ": ";
    st += WiFi.SSID(i);
    st += " (";
    st += WiFi.RSSI(i);
    st += ")";
    st += (WiFi.encryptionType(i) == ENC_TYPE_NONE) ? " " : "*";
    st += "</li>";
  }
  st += "</ul>";
  delay(100);
  char APssid[hostName.length() + 1];
  memset(APssid, 0, hostName.length() + 1);
  for (int i = 0; i < hostName.length(); i++) {
	APssid[i] = hostName.charAt(i);  
  }
  WiFi.softAP(APssid, APpsk);
  Serial.println("Initiating Soft AP");
  Serial.println("");
  WebServiceInit();
  WebServiceDaemon(1);
}

void UpdatePlugNLED(int plug, int value) {
  if (value != 0){
	value = 100;
  }
  digitalWrite(SWITCH_LED, value);
  digitalWrite(plug, value);
  NotificationBroadcast(plug, value);
}

void Broadcast(void) {
  // Set the broadcast address
  IPAddress ip = WiFi.localIP();
  for (int i = 0; i < 3; i++) {
    bcast[i] = ip[i];
  }
  bcast[3] = 255;
  
  // thingTronics|thingSocket-ABCDEF|v0.1:v1.1|totalResources|
  // Building up the Broadcast message
  String brdcast_msg;
  brdcast_msg += company_name;
  brdcast_msg += "|";
  brdcast_msg += hostName;
  brdcast_msg += "|";
  brdcast_msg += hardware_version;
  brdcast_msg += ":";
  brdcast_msg += software_version;
  brdcast_msg += "|";
  brdcast_msg += String(MAX_RESOURCES);
  brdcast_msg += "|";
  Udp.beginPacket(bcast, BROADCAST_PORT);
  Udp.write(brdcast_msg.c_str());
  yield();
  delay(1);
  Udp.endPacket();
#ifdef DEBUG
  Serial.println(brdcast_msg);
#endif  
}

void NotificationBroadcast(int which_plug, int state) {
  //thingTronics|thingSocket-ABCDEF|zone|type|name|magicResourceNumber|value|
  // Building up the Notification message
  String notif_msg;
  notif_msg += company_name;
  notif_msg += "|";
  notif_msg += hostName;
  notif_msg += "|";
  notif_msg += zone;
  notif_msg += "|";
  notif_msg += appl_type;
  notif_msg += "|";
  notif_msg += appl_name;
  notif_msg += "|";
  notif_msg += String(resource_number);
  notif_msg += "|";
  notif_msg += String((state > 0) ? "100|" : "0|");
  if(configure_flag) {
    notif_msg += "CONFIGURED|";
    configure_flag = false;
  }
  // Add this jugglery for sending complete packets
  unsigned int len = notif_msg.length();
  
  byte* msg_buf = (byte*)malloc(len);
  memcpy(msg_buf, notif_msg.c_str(), len);
  
  Udp.beginPacket(bcast, NOTIFICATION_PORT);
  Udp.write(msg_buf, len);
  Udp.endPacket();
#ifdef DEBUG  
  Serial.println(notif_msg);
#endif  
}

/**
 * Perform URL percent decoding.
 * Decoding is done in-place and will modify the parameter.
 */
void UrlDecode(char *src) {
  char *dst = src;
  while (*src) {
    if (*src == '+') {
      src++;
      *dst++ = ' ';
    }
    else if (*src == '%') {
      // handle percent escape
      *dst = '\0';
      src++;
      if (*src >= '0' && *src <= '9') {
        *dst = *src++ - '0';
      }
      else if (*src >= 'A' && *src <= 'F') {
        *dst = 10 + *src++ - 'A';
      }
      else if (*src >= 'a' && *src <= 'f') {
        *dst = 10 + *src++ - 'a';
      }
      // this will cause %4 to be decoded to ascii @, but %4 is invalid
      // and we can't be expected to decode it properly anyway
      *dst <<= 4;
      if (*src >= '0' && *src <= '9') {
        *dst |= *src++ - '0';
      }
      else if (*src >= 'A' && *src <= 'F') {
        *dst |= 10 + *src++ - 'A';
      }
      else if (*src >= 'a' && *src <= 'f') {
        *dst |= 10 + *src++ - 'a';
      }
      dst++;
    }
    else {
      *dst++ = *src++;
    }
  }
  *dst = '\0';
}

void pin_ISR() {
  detachInterrupt(digitalPinToInterrupt(SWITCH));
#ifdef DEBUG  
  String s;
  s += "ISR Called ";
  s += String(num);
  Serial.println(s);
  num++;
#endif
  
  myDelay(250);
  volatile int buttonState = digitalRead(SWITCH);
  UpdatePlugNLED(PLUG, !buttonState);
  attachInterrupt(digitalPinToInterrupt(SWITCH), pin_ISR, CHANGE);
}

void myDelay(int x) {
  for(int i=0; i<=x; i++) {
    delayMicroseconds(1000);
  }
}
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

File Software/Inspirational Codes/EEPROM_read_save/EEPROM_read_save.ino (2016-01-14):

#include <ESP8266WiFi.h>
#include <ESP8266mDNS.h>
#include <WiFiClient.h>
#include <EEPROM.h>

MDNSResponder mdns;
WiFiServer server(80);

const char* ssid = "Smart-Plug";
String st;

void setup() {
  Serial.begin(115200);
  EEPROM.begin(512);
  delay(10);
  Serial.println();
  Serial.println();
  Serial.println("Startup");
  // read eeprom for ssid and pass
  Serial.println("Reading EEPROM ssid");
  String esid;
  for (int i = 0; i < 32; ++i)
    {
      esid += char(EEPROM.read(i));
    }
  Serial.print("SSID: ");
  Serial.println(esid);
  Serial.println("Reading EEPROM pass");
  String epass = "";
  for (int i = 32; i < 96; ++i)
    {
      epass += char(EEPROM.read(i));
    }
  Serial.print("PASS: ");
  Serial.println(epass);  
  if ( esid.length() > 1 ) {
      // test esid 
      WiFi.begin(esid.c_str(), epass.c_str());
      if ( testWifi() == 20 ) { 
          Serial.println("starting testing wifi connection");
          launchWeb(0);
          return;
      }
  }
  setupAP(); 
}

int testWifi(void) {
  int c = 0;
  Serial.println("Waiting for Wifi to connect");  
  while ( c < 20 ) {
    if (WiFi.status() == WL_CONNECTED) { return(20); } 
    delay(500);
    Serial.print(WiFi.status());    
    c++;
  }
  Serial.println("Connect timed out, opening AP");
  return(10);
} 

void launchWeb(int webtype) {
          Serial.println("");
          Serial.println("WiFi connected");
          Serial.println(WiFi.localIP());
          Serial.println(WiFi.softAPIP());
          
//          if (!mdns.begin("esp8266",WiFi.localIP())) {
//            Serial.println("Error setting up MDNS responder!");
//            while(1) { 
//              delay(1000);
//            }
//          }
//          Serial.println("mDNS responder started");
          // Start the server
          server.begin();
          Serial.println("Server started");   
          int b = 20;
          int c = 0;
          while(b == 20) { 
             b = mdns_service(webtype);
           }
}

void setupAP(void) {
  
  WiFi.mode(WIFI_STA);
  WiFi.disconnect();
  delay(100);
  int n = WiFi.scanNetworks();
  Serial.println("scan done");
  if (n == 0)
    Serial.println("no networks found");
  else
  {
    Serial.print(n);
    Serial.println(" networks found");
    for (int i = 0; i < n; ++i)
     {
      // Print SSID and RSSI for each network found
      Serial.print(i + 1);
      Serial.print(": ");
      Serial.print(WiFi.SSID(i));
      Serial.print(" (");
      Serial.print(WiFi.RSSI(i));
      Serial.print(")");
      Serial.println((WiFi.encryptionType(i) == ENC_TYPE_NONE)?" ":"*");
      delay(10);
     }
  }
  Serial.println(""); 
  st = "<ul>";
  for (int i = 0; i < n; ++i)
    {
      // Print SSID and RSSI for each network found
      st += "<li>";
      st +=i + 1;
      st += ": ";
      st += WiFi.SSID(i);
      st += " (";
      st += WiFi.RSSI(i);
      st += ")";
      st += (WiFi.encryptionType(i) == ENC_TYPE_NONE)?" ":"*";
      st += "</li>";
    }
  st += "</ul>";
  delay(100);
  WiFi.softAP(ssid);
  Serial.println("softap");
  Serial.println("");
  launchWeb(1);
  Serial.println("over");
}

int mdns_service(int webtype)
{
  // Check for any mDNS queries and send responses
//  mdns.update();
  // Add service to MDNS-SD
  //MDNS.addService("http", "tcp", 80);
  
  // Check if a client has connected
  WiFiClient client = server.available();
  if (!client) {
    return(20);
  }
  Serial.println("");
  Serial.println("New client");

  // Wait for data from client to become available
  while(client.connected() && !client.available()){
    delay(1);
   }
  
  // Read the first line of HTTP request
  String req = client.readStringUntil('\r');
  
  // First line of HTTP request looks like "GET /path HTTP/1.1"
  // Retrieve the "/path" part by finding the spaces
  int addr_start = req.indexOf(' ');
  int addr_end = req.indexOf(' ', addr_start + 1);
  if (addr_start == -1 || addr_end == -1) {
    Serial.print("Invalid request: ");
    Serial.println(req);
    return(20);
   }
  req = req.substring(addr_start + 1, addr_end);
  Serial.print("Request: ");
  Serial.println(req);
  client.flush(); 
  String s;
  if ( webtype == 1 ) {
      if (req == "/")
      {
        IPAddress ip = WiFi.softAPIP();
        String ipStr = String(ip[0]) + '.' + String(ip[1]) + '.' + String(ip[2]) + '.' + String(ip[3]);
        s = "HTTP/1.1 200 OK\r\nContent-Type: text/html\r\n\r\n<!DOCTYPE HTML>\r\n<html>Hello from ESP8266 at ";
        s += ipStr;
        s += "<p>";
        s += st;
        s += "<form method='get' action='a'><label>SSID: </label><input name='ssid' length=32><input name='pass' length=64><input type='submit'></form>";
        s += "</html>\r\n\r\n";
        Serial.println("Sending 200");
      }
      else if ( req.startsWith("/a?ssid=") ) {
        // /a?ssid=blahhhh&pass=poooo
        Serial.println("clearing eeprom");
        for (int i = 0; i < 96; ++i) { EEPROM.write(i, 0); }
        String qsid; 
        qsid = req.substring(8,req.indexOf('&'));
        Serial.println(qsid);
        Serial.println("");
        String qpass;
        qpass = req.substring(req.lastIndexOf('=')+1);
        Serial.println(qpass);
        Serial.println("");
        
        Serial.println("writing eeprom ssid:");
        for (int i = 0; i < qsid.length(); ++i)
          {
            EEPROM.write(i, qsid[i]);
            Serial.print("Wrote: ");
            Serial.println(qsid[i]); 
          }
        Serial.println("writing eeprom pass:"); 
        for (int i = 0; i < qpass.length(); ++i)
          {
            EEPROM.write(32+i, qpass[i]);
            Serial.print("Wrote: ");
            Serial.println(qpass[i]); 
          }    
        EEPROM.commit();
        s = "HTTP/1.1 200 OK\r\nContent-Type: text/html\r\n\r\n<!DOCTYPE HTML>\r\n<html>Hello from ESP8266 ";
        s += "Found ";
        s += req;
        s += "<p> saved to eeprom... reset to boot into new wifi</html>\r\n\r\n";
      }
      else
      {
        s = "HTTP/1.1 404 Not Found\r\n\r\n";
        Serial.println("Sending 404");
      }
  } 
  else
  {
      if (req == "/")
      {
        s = "HTTP/1.1 200 OK\r\nContent-Type: text/html\r\n\r\n<!DOCTYPE HTML>\r\n<html>Hello from ESP8266";
        s += "<p>";
        s += "</html>\r\n\r\n";
        Serial.println("Sending 200");
      }
      else if ( req.startsWith("/cleareeprom") ) {
        s = "HTTP/1.1 200 OK\r\nContent-Type: text/html\r\n\r\n<!DOCTYPE HTML>\r\n<html>Hello from ESP8266";
        s += "<p>Clearing the EEPROM<p>";
        s += "</html>\r\n\r\n";
        Serial.println("Sending 200");  
        Serial.println("clearing eeprom");
        for (int i = 0; i < 96; ++i) { EEPROM.write(i, 0); }
        EEPROM.commit();
      }
      else
      {
        s = "HTTP/1.1 404 Not Found\r\n\r\n";
        Serial.println("Sending 404");
      }       
  }
  client.print(s);
  Serial.println("Done with client");
  return(20);
}
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

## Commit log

2016-01-08 added rebooting feature on connection drop
    [smart-plugv0.5.ino]
2016-02-04 added hardware folder and minor changes to code
    [thingSocketv0.1.brd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]
2016-02-04 added date to hardware files
    [thingSocketv0.1.brd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]
2016-02-16 adding support for switch and LED in thingSocketv1.0
2016-03-03 edited broadcast and notification msg + included mac addition to device name
2016-05-15 version 0.2 started
    [thingSocketv0.2.brd, thingSocketv0.2.sch]
2016-10-16 unified the resource mechanism; added device password
    [thingSocketv0.2.sch]
2016-10-21 removed the update bug.
    [thingSocketv2.0.ino]
2016-11-02 added default mechanism for factory reset
    [thingSocketv0.2.sch]
2016-11-04 minor correction to the PLUG GPIO
    [thingSocketv2.0.ino]

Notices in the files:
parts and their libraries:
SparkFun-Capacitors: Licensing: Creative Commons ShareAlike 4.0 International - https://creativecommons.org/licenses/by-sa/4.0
